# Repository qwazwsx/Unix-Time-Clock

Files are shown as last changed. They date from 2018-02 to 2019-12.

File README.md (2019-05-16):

# Introduction

This project is a fork of [Maniacal Labs Super 7 Seg](https://github.com/ManiacalLabs/Super7Seg). Please refer to that project's README for the full details of that project.

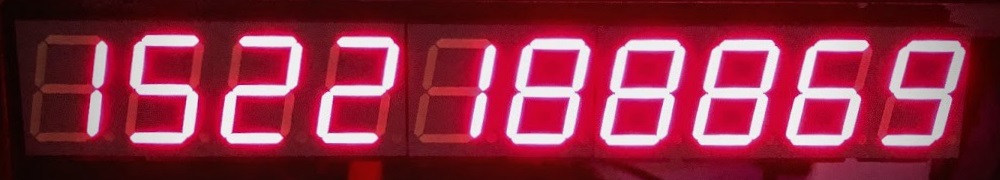
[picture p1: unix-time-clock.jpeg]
Unix Time Clock


My fork was designed with one project in mind - creating a [Unix Time Clock](https://mylifeasa.tinkerer.us/unix-time-clock-57b17d05442e). To accomplish this, I changed the [display hardware](https://github.com/dwaq/Super7Seg/tree/master/kicad/Super7Display) from 6x dual segment displays to 5x displays (12 digits to 10 digits) and changed the [controller hardware](https://github.com/dwaq/Super7Seg/tree/master/kicad/Super7Controller) from a ATMega328p to ESP32. The [Arduino firmware](https://github.com/dwaq/Super7Seg/tree/master/Firmware-ESP32) for this project is also in this repo, along with the [3D models](https://github.com/dwaq/Super7Seg/tree/master/Mount-ESP32) for mounting the project.

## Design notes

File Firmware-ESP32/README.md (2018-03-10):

# Installation & Setup Instructions

1. Copy `credentials-example.h` to `credentials.h` and fill in WiFi SSID and password
2. Adjust `#define PWM_BRIGHTNESS 255` in `display.c` if you want reduced display brightness
3. Install [Arduino core for the ESP32](https://github.com/espressif/arduino-esp32#installation-instructions)
4. Set board to "ESP32 Dev Module"
5. Select port
6. Upload code

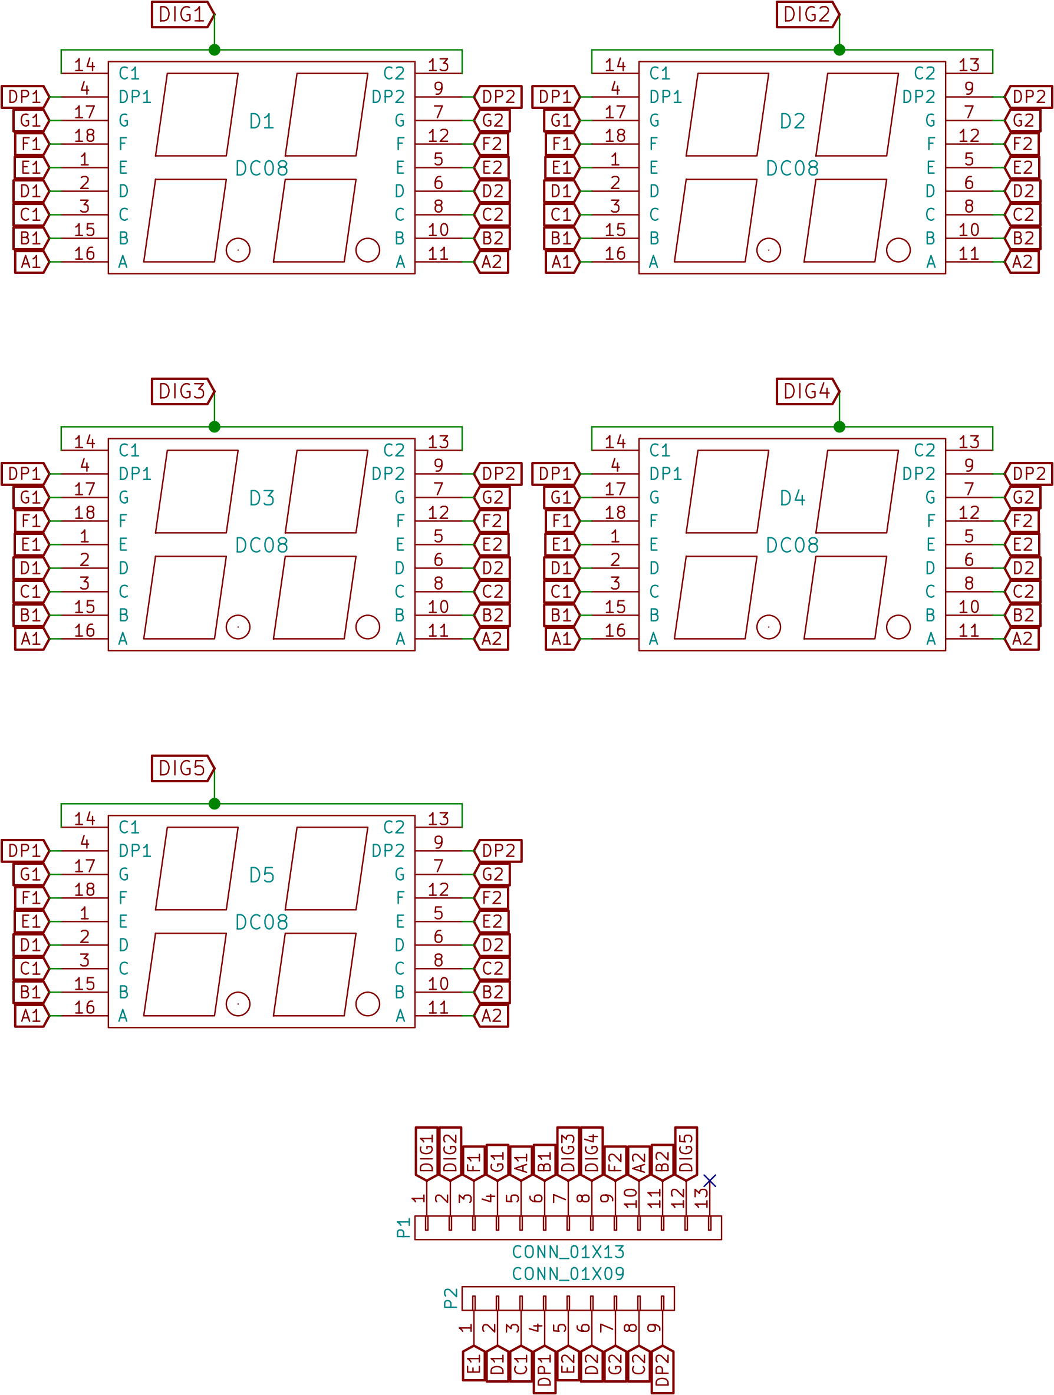
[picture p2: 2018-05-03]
kicad/Super7Display/Super7Display.sch.png

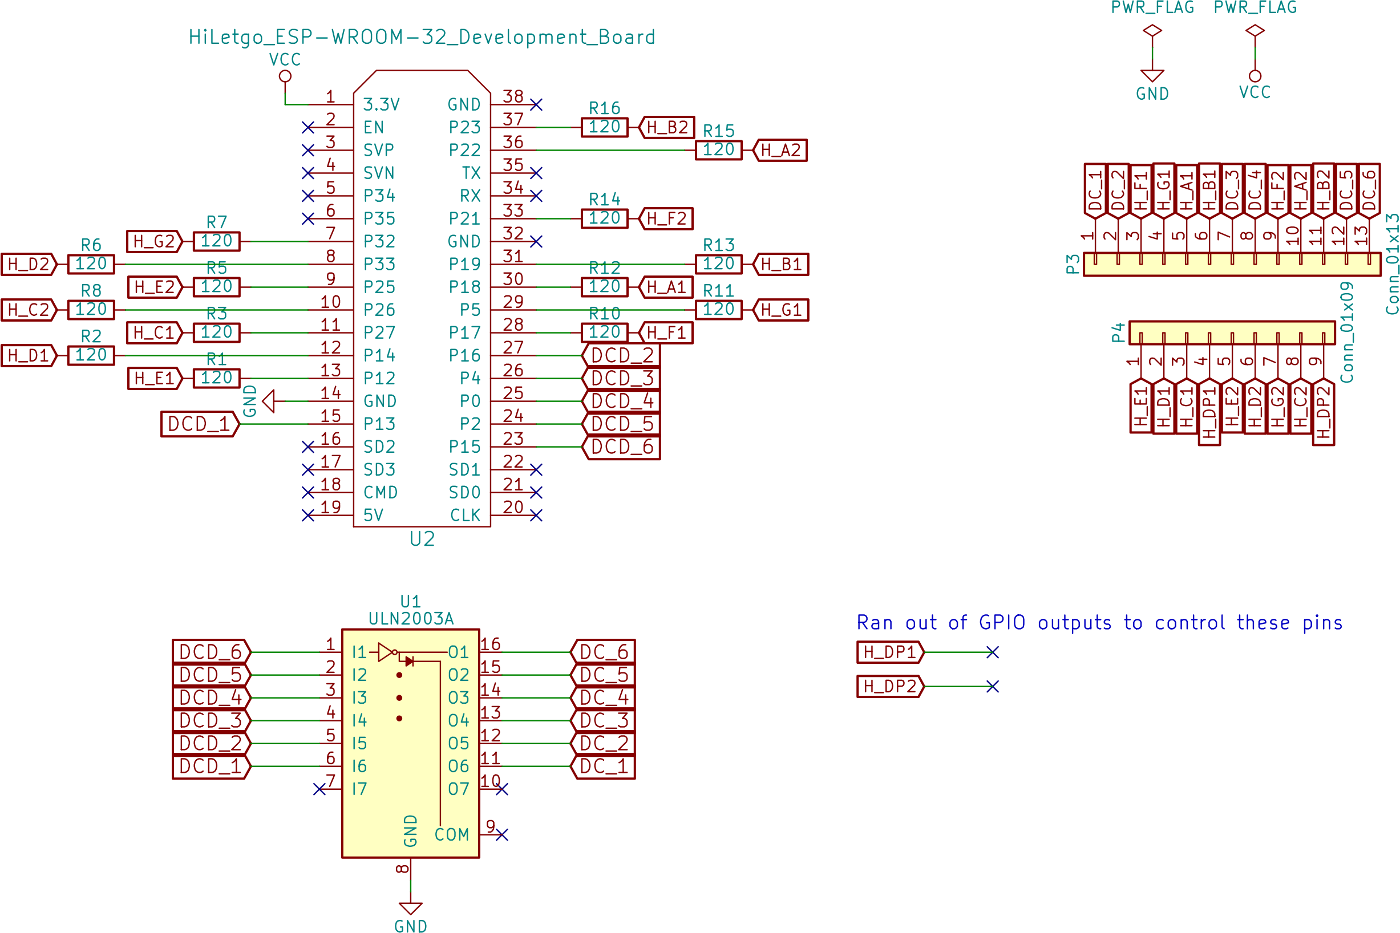
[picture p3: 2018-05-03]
kicad/Super7Controller/Super7Controller.sch.png

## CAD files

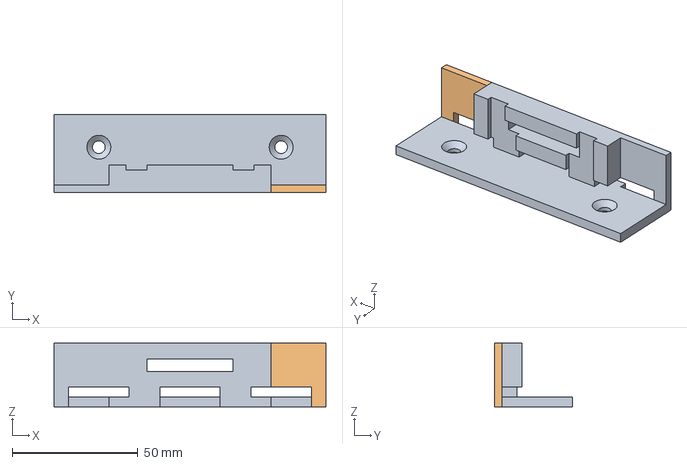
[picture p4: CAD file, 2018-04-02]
Mount-ESP32/Mount.step
108.0 x 31.0 x 25.2 mm

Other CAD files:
Mount-ESP32/Mount.f3d
Mount-ESP32/Mount.stl

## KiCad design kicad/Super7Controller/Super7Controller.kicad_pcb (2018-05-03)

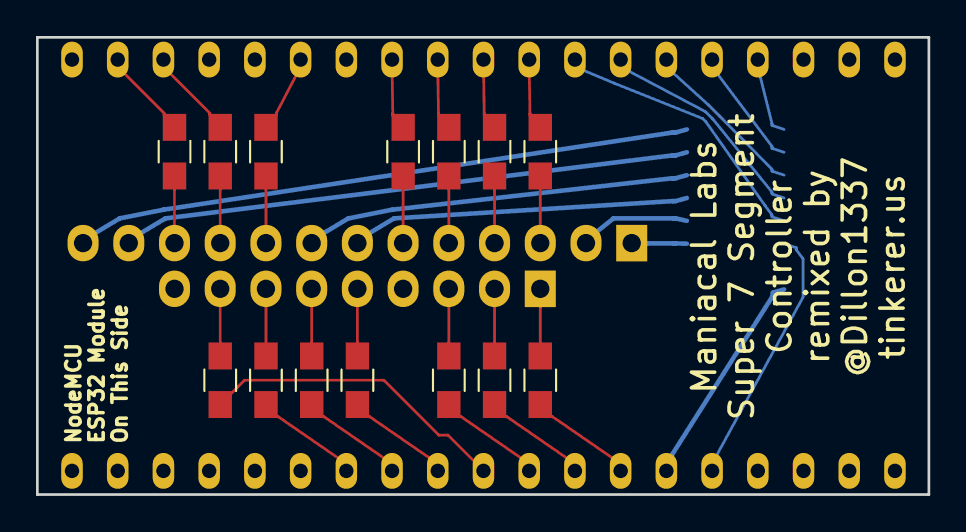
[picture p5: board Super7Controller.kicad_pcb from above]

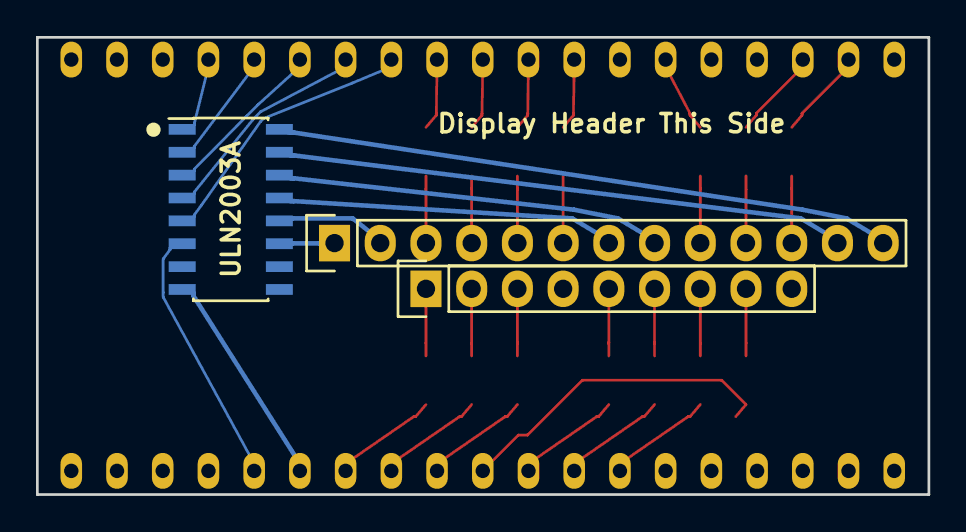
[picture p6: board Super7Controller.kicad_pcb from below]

Board: 2 copper layers, 49.5 x 25.4 mm, 18 parts (3 on the bottom side), 41 nets.

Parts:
P3: Conn_01x13; Socket_Strip_Straight_1x13
P4: Conn_01x09; Socket_Strip_Straight_1x09
R1, R2, R3, R5, R6, R7, R8, R10, R11, R12, R13, R14, R15, R16: 120; R_0805_HandSoldering
U1: ULN2003A; SOIC-16_3.9x9.9mm_Pitch1.27mm
U2: HiLetgo_ESP-WROOM-32_Development_Board; hiletgo_esp-wroom-32_development_board

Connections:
DCD_1: U1.6, U2.15
DCD_2: U1.5, U2.27
DCD_3: U1.4, U2.26
DCD_4: U1.3, U2.25
DCD_5: U1.2, U2.24
DCD_6: U1.1, U2.23
DC_1: P3.1, U1.11
DC_2: P3.2, U1.12
DC_3: P3.7, U1.13
DC_4: P3.8, U1.14
DC_5: P3.12, U1.15
DC_6: P3.13, U1.16
GND: U1.8, U2.14
H_A1: P3.5, R12.2
H_A2: P3.10, R15.2
H_B1: P3.6, R13.2
H_B2: P3.11, R16.2
H_C1: P4.3, R3.2
H_C2: P4.8, R8.2
H_D1: P4.2, R2.2
H_D2: P4.6, R6.2
H_E1: P4.1, R1.2
H_E2: P4.5, R5.2
H_F1: P3.3, R10.2
H_F2: P3.9, R14.2
H_G1: P3.4, R11.2
H_G2: P4.7, R7.2
unnamed: R1.1, U2.13
unnamed: R2.1, U2.12
unnamed: R3.1, U2.11
unnamed: R5.1, U2.9
unnamed: R6.1, U2.8
unnamed: R7.1, U2.7
unnamed: R8.1, U2.10
unnamed: R10.1, U2.28
unnamed: R11.1, U2.29
unnamed: R12.1, U2.30
unnamed: R13.1, U2.31
unnamed: R14.1, U2.33
unnamed: R15.1, U2.36
unnamed: R16.1, U2.37

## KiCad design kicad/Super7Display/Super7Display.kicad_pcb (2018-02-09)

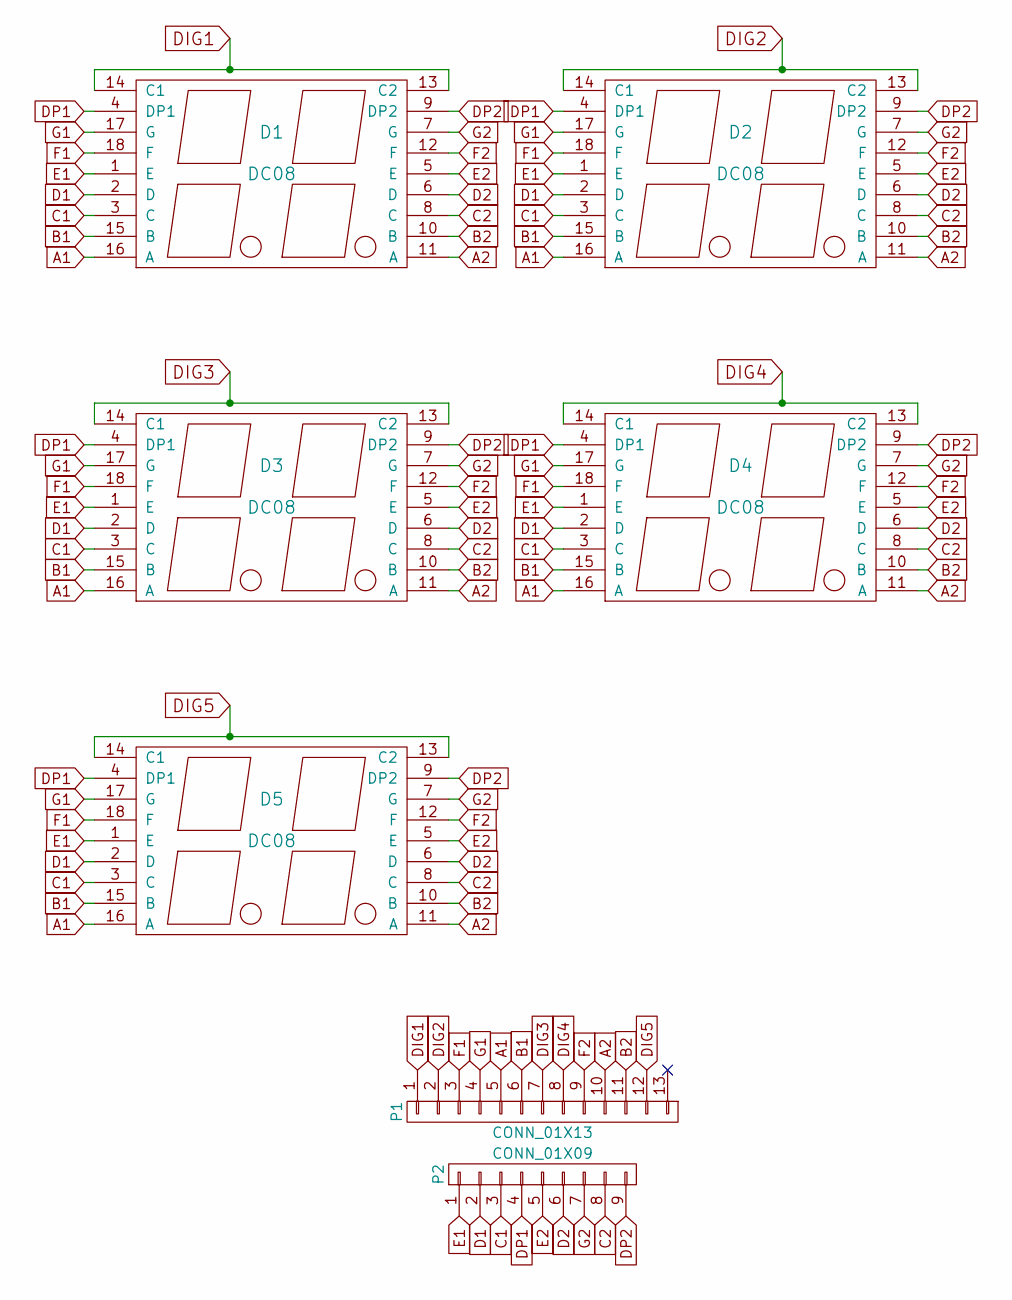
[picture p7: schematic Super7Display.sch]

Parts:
D1, D2, D3, D4, D5: DC08
P1: CONN_01X13; Socket_Strip_Straight_1x13
P2: CONN_01X09; Socket_Strip_Straight_1x09

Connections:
A1: D1.16 (A), D2.16 (A), D3.16 (A), D4.16 (A), D5.16 (A), P1.5
A2: D1.11 (A), D2.11 (A), D3.11 (A), D4.11 (A), D5.11 (A), P1.10
B1: D1.15 (B), D2.15 (B), D3.15 (B), D4.15 (B), D5.15 (B), P1.6
B2: D1.10 (B), D2.10 (B), D3.10 (B), D4.10 (B), D5.10 (B), P1.11
C1: D1.3 (C), D2.3 (C), D3.3 (C), D4.3 (C), D5.3 (C), P2.3
C2: D1.8 (C), D2.8 (C), D3.8 (C), D4.8 (C), D5.8 (C), P2.8
D1: D1.2 (D), D2.2 (D), D3.2 (D), D4.2 (D), D5.2 (D), P2.2
D2: D1.6 (D), D2.6 (D), D3.6 (D), D4.6 (D), D5.6 (D), P2.6
DIG1: D1.13 (C2), D1.14 (C1), P1.1
DIG2: D2.13 (C2), D2.14 (C1), P1.2
DIG3: D3.13 (C2), D3.14 (C1), P1.7
DIG4: D4.13 (C2), D4.14 (C1), P1.8
DIG5: D5.13 (C2), D5.14 (C1), P1.12
DP1: D1.4 (DP1), D2.4 (DP1), D3.4 (DP1), D4.4 (DP1), D5.4 (DP1), P2.4
DP2: D1.9 (DP2), D2.9 (DP2), D3.9 (DP2), D4.9 (DP2), D5.9 (DP2), P2.9
E1: D1.1 (E), D2.1 (E), D3.1 (E), D4.1 (E), D5.1 (E), P2.1
E2: D1.5 (E), D2.5 (E), D3.5 (E), D4.5 (E), D5.5 (E), P2.5
F1: D1.18 (F), D2.18 (F), D3.18 (F), D4.18 (F), D5.18 (F), P1.3
F2: D1.12 (F), D2.12 (F), D3.12 (F), D4.12 (F), D5.12 (F), P1.9
G1: D1.17 (G), D2.17 (G), D3.17 (G), D4.17 (G), D5.17 (G), P1.4
G2: D1.7 (G), D2.7 (G), D3.7 (G), D4.7 (G), D5.7 (G), P2.7

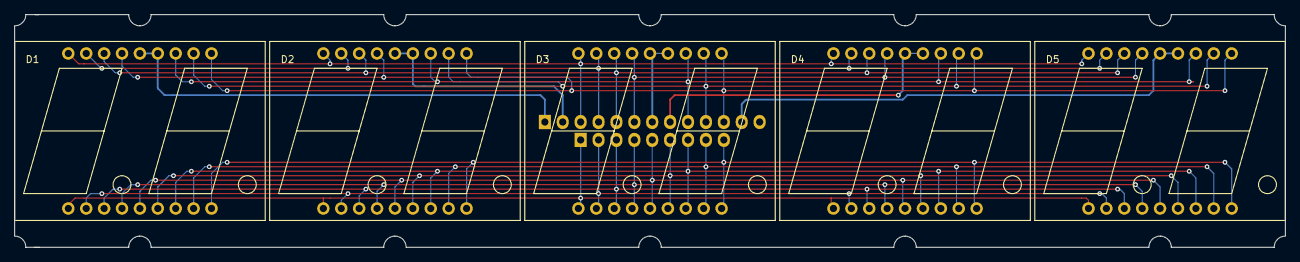
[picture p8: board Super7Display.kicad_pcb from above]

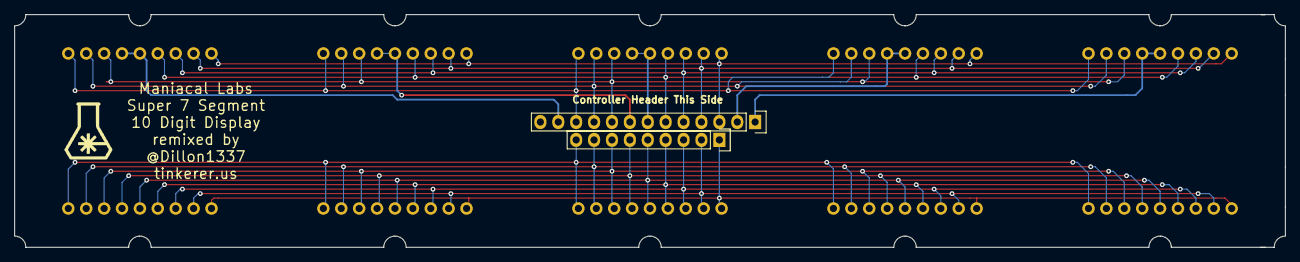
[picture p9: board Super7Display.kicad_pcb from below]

Board: 2 copper layers, 180.3 x 33.0 mm, 7 parts (2 on the bottom side), 21 nets.

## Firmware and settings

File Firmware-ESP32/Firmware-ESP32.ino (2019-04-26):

#include "getTime.h"
#include "display.h"

void setup() {
  // set up the display pins
  displaySetup();

  // start background task to get time from internet
  // normal tasks run on core 1, so run on other core - core 0
  xTaskCreatePinnedToCore(
    coreTask,   // Function to call
    "coreTask", // Name of the task
    10000,      // Stack size in words
    NULL,       // Task input parameter
    0,          // Priority of the task
    NULL,       // Task handle
    0);         // Core where the task should run

  // display connecting animation until time is set in the background
  displayConnecting();
}

void loop() {
  // get the current time and display the digits on the display
  getAndDisplayTime();
}

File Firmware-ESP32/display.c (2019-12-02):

#include "display.h"
#include "getTime.h"

// PWM settings for display brightness
// max of 255, but can reduce for a less bright display
#define PWM_BRIGHTNESS 255
// shouldn't need to change these:
#define PWM_FREQ 5000
#define PWM_RESOLUTION 8

// pinouts for common cathode 7 segment LED display:

// segment is active high
// segment | ESP32 pin
#define SEG_A1  18
#define SEG_B1  19
#define SEG_C1  27
#define SEG_D1  14
#define SEG_E1  12
#define SEG_F1  17
#define SEG_G1  5
//#define SEG_DP1 26

#define SEG_A2  22
#define SEG_B2  23
#define SEG_C2  26
#define SEG_D2  33
#define SEG_E2  25
#define SEG_F2  21
#define SEG_G2  32
//#define SEG_DP2 34

// digit is active high
// digit | ESP32 pin
#define DC_1  13
#define DC_2  16
#define DC_3  4
#define DC_4  0
#define DC_5  2
#define DC_6  15

// PWM channels cooresponding to digits
#define D_PWM_1  1
#define D_PWM_2  2
#define D_PWM_3  3
#define D_PWM_4  4
#define D_PWM_5  5
#define D_PWM_6  6

// set display pins to outputs
void displaySetup()
{
  pinMode(SEG_A1, OUTPUT);
  pinMode(SEG_B1, OUTPUT);
  pinMode(SEG_C1, OUTPUT);
  pinMode(SEG_D1, OUTPUT);
  pinMode(SEG_E1, OUTPUT);
  pinMode(SEG_F1, OUTPUT);
  pinMode(SEG_G1, OUTPUT);
  //pinMode(SEG_DP1, OUTPUT);

  pinMode(SEG_A2, OUTPUT);
  pinMode(SEG_B2, OUTPUT);
  pinMode(SEG_C2, OUTPUT);
  pinMode(SEG_D2, OUTPUT);
  pinMode(SEG_E2, OUTPUT);
  pinMode(SEG_F2, OUTPUT);
  pinMode(SEG_G2, OUTPUT);
  //pinMode(SEG_DP2, OUTPUT);

  // set up PWM on digits
  ledcAttachPin(DC_1, D_PWM_1);
  ledcSetup(D_PWM_1, PWM_FREQ, PWM_RESOLUTION);

  ledcAttachPin(DC_2, D_PWM_2);
  ledcSetup(D_PWM_2, PWM_FREQ, PWM_RESOLUTION);

  ledcAttachPin(DC_3, D_PWM_3);
  ledcSetup(D_PWM_3, PWM_FREQ, PWM_RESOLUTION);

  ledcAttachPin(DC_4, D_PWM_4);
  ledcSetup(D_PWM_4, PWM_FREQ, PWM_RESOLUTION);

  ledcAttachPin(DC_5, D_PWM_5);
  ledcSetup(D_PWM_5, PWM_FREQ, PWM_RESOLUTION);

  //ledcAttachPin(DC_6, D_PWM_6);
  //ledcSetup(D_PWM_6, PWM_FREQ, PWM_RESOLUTION);
}

// use middle segment as 10th "number" to display
#define CONNECTING 10

// delay between progress bar animations
#define CONNECTING_DELAY 100
// shortest delay so all displays are on for the same amount of time
#define DELAYTIME 1

// display a progress bar for WiFi connecting animation
void displayConnecting(void)
{
  // go right if 1; left if 0
  int right = 1;
  // index of display to light
  int n = 1;

  // continue displaying until time has been set
  while(isConnecting())
  {
    // display connecting bars "--" on n-th display
    selectDisplay(n, CONNECTING, CONNECTING);

    // count 1, 2, 3, 4, 5, 4, 3, 2
    // and then repeat
    if ((right==1) && (n<=5))
    {
      n++;
      if (n==5)
      {
        right=0;
      }
    }
    else if ((right==0) && (n>=1))
    {
      n--;
      if (n==1)
      {
        right=1;
        n=1;
      }
    }

    // each display is on for 1/10 second
    delay(CONNECTING_DELAY);
  }

  // unix time right now
  int unix_time_now = time(NULL);

  // loop until the time changes
  // while displaying all bars "----------"
  while (time(NULL) == unix_time_now)
  {
    // display connecting bars "--" on n-th display
    selectDisplay(n, CONNECTING, CONNECTING);

    // count 1, 2, 3, 4, 5
    // and then repeat
    n++;
    if (n==6)
    {
      n=1;
    }

    // shortest delay
    delay(DELAYTIME);
  }

  // start a 1 hour timer to re-sync the time from the internet
  startHardwareTimer();
}

// cycle through and display the time across all digits
void getAndDisplayTime(void)
{
  // get the current time
  unsigned int unix_time = getTime();

  // loop through the time and set each digit:

  // get lowest digit
  byte firstDigit = unix_time % 10;
  // shift over
  unix_time = unix_time / 10;
  // get next lowest digit
  byte secondDigit = unix_time % 10;
  // shift over agin for the next round
  unix_time = unix_time / 10;

  // digits are assigned right to left (LSB first)
  // digits 2 & 1
  selectDisplay(5, secondDigit, firstDigit);
  delay(DELAYTIME);

  // continue looping over the remaining digits:

  // digits 4 & 3
  firstDigit = unix_time % 10;
  unix_time = unix_time / 10;
  secondDigit = unix_time % 10;
  unix_time = unix_time / 10;
  selectDisplay(4, secondDigit, firstDigit);
  delay(DELAYTIME);

  // digits 6 & 5
  firstDigit = unix_time % 10;
  unix_time = unix_time / 10;
  secondDigit = unix_time % 10;
  unix_time = unix_time / 10;
  selectDisplay(3, secondDigit, firstDigit);
  delay(DELAYTIME);

  // digits 8 & 7
  firstDigit = unix_time % 10;
  unix_time = unix_time / 10;
  secondDigit = unix_time % 10;
  unix_time = unix_time / 10;
  selectDisplay(2, secondDigit, firstDigit);
  delay(DELAYTIME);

  // digits 10 & 9
  firstDigit = unix_time % 10;
  unix_time = unix_time / 10;
  secondDigit = unix_time % 10;
  unix_time = unix_time / 10;
  selectDisplay(1, secondDigit, firstDigit);
  delay(DELAYTIME);
}

// display a number on the selected display
// display can be between 1-5
// numbers can be between 0-9, and 10 is "--" for connecting
void selectDisplay(int display, byte number1, byte number2)
{
  // turn all digits off (PWM duty cycle = 0)
  ledcWrite(D_PWM_1, 0);
  ledcWrite(D_PWM_2, 0);
  ledcWrite(D_PWM_3, 0);
  ledcWrite(D_PWM_4, 0);
  ledcWrite(D_PWM_5, 0);
  //ledcWrite(D_PWM_6, 0);

  // set up segments while digits off,
  // so that the full digit comes up simultanously
  // (although who is going to be able to detect a couple clk cycles?)
  resetSegments();
  setSegment1(number1);
  setSegment2(number2);

  // then turn on specfic digit
  switch(display)
  {
    case 1:
      ledcWrite(D_PWM_1, PWM_BRIGHTNESS);
      break;
    case 2:
      ledcWrite(D_PWM_2, PWM_BRIGHTNESS);
      break;
    case 3:
      ledcWrite(D_PWM_3, PWM_BRIGHTNESS);
      break;
    case 4:
      ledcWrite(D_PWM_4, PWM_BRIGHTNESS);
      break;
    case 5:
      ledcWrite(D_PWM_5, PWM_BRIGHTNESS);
      break;
    //default:
      // bad - should't be here
  }
}

// reset all segments
void resetSegments(void)
{
  digitalWrite(SEG_A1, LOW);
  digitalWrite(SEG_B1, LOW);
  digitalWrite(SEG_C1, LOW);
  digitalWrite(SEG_D1, LOW);
  digitalWrite(SEG_E1, LOW);
  digitalWrite(SEG_F1, LOW);
  digitalWrite(SEG_G1, LOW);

  digitalWrite(SEG_A2, LOW);
  digitalWrite(SEG_B2, LOW);
  digitalWrite(SEG_C2, LOW);
  digitalWrite(SEG_D2, LOW);
  digitalWrite(SEG_E2, LOW);
  digitalWrite(SEG_F2, LOW);
  digitalWrite(SEG_G2, LOW);
}
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

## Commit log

2018-01-30 Remove DIG6 from schematic
    [Super7Display.sch]
2018-01-30 Remove D6 from layout
    Move right edge into place
    Top and bottom edges still need adjusted
    [Super7Display.kicad_pcb]
2018-01-30 Move mounting tabs above/below D1, D3, D5
    [Super7Display.kicad_pcb]
2018-01-30 use built-in ULN2003
    [_saved_Super7Controller.sch]
2018-01-30 DC6 is gone
    [Super7Controller.sch, _saved_Super7Controller.sch]
2018-01-30 added no connect on unused segment connector
    [Super7Display.sch]
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2018-01-31 connect ESP dev board on schematic
    [Super7Controller.sch]
2018-01-31 change resistors to surface mount
    [Super7Controller.sch]
2018-01-31 use old symbol for ULN2003A because GND is needed
    [Super7Controller.sch]
2018-01-31 change ESP pins to bidirectional to pass ERC
    [Super7Controller.sch]
2018-01-31 use SOIC footprint for ULN
    [Super7Controller.sch]
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2018-02-08 assign esp32 footprint to schematic symbol
    [Super7Controller.sch]
2018-02-08 add no connects to unused pins
    [Super7Controller.sch]
2018-02-08 read new netlist and delete all the old stuff
    [Super7Controller.kicad_pcb]
2018-02-08 remove some extra silkscreen
    [Super7Controller.kicad_pcb]
2018-02-08 move around
    [Super7Controller.kicad_pcb]
2018-02-08 move reference inside board
    [Super7Controller.kicad_pcb]
2018-02-08 add anchor
    [Super7Controller.kicad_pcb]
2018-02-08 add anchor to display also
    [Super7Display.kicad_pcb]
2018-02-08 export layout
    [Super7Controller.dsn]
2018-02-08 these ESP32 GPIOs are swappable
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2018-02-08 imported routes into kicad
    [Super7Controller.kicad_pcb]
2018-02-08 all resistor inputs are swappable
2018-02-08 make resistor inputs gate swappable
2018-02-08 move ULN to the back
    [Super7Controller.dsn, Super7Controller.kicad_pcb]
2018-02-08 import routed design into KiCad
    [Super7Controller.kicad_pcb]
2018-02-08 adjust edge cuts and remove unneeded parts
    [Super7Controller.kicad_pcb]
2018-02-08 only need one ground connection from ESP to ULN
    [Super7Controller.sch]
2018-02-08 reroute lines to match autorouter
    [Super7Controller.sch]
2018-02-08 read new netlist, some errors left
    [Super7Controller.kicad_pcb]
2018-02-08 correct errors in netlist
    [Super7Controller.kicad_pcb, Super7Controller.sch]
2018-02-08 replace long ground trace with something shorter
    [Super7Controller.kicad_pcb]
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2018-02-08 move resistor connections to make routing easier
    [Super7Controller.sch]
2018-02-08 move ULN connections to make routing easier
    [Super7Controller.sch]
2018-02-08 export netlist into layout and remove already routed lines
    [Super7Controller.kicad_pcb]
2018-02-08 autorouter worked well on resistors, ULN needs work
    [Super7Controller.dsn]
2018-02-08 move the ULN up a little
    [Super7Controller.dsn, Super7Controller.kicad_pcb]
2018-02-08 2 to 6 is better
    [Super7Controller.dsn, Super7Controller.kicad_pcb, Super7Controller.sch]
2018-02-08 Autoroute it and put it back into KiCad
    [Super7Controller.dsn, Super7Controller.kicad_pcb]
2018-02-08 remove/hide top layer silkscreen
    [Super7Controller.kicad_pcb]
2018-02-08 move silkscreen away from lines
    [Super7Controller.kicad_pcb]
2018-02-08 new gerbers lookin' good
    [Super7Controller-B.Cu.gbr, Super7Controller-B.Mask.gbr, Super7Controller-B.SilkS.gbr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]
2018-02-08 use new KiCad header instead of old one
    [Super7Controller.kicad_pcb, Super7Controller.sch]
2018-02-08 Add silkscreen for ESP32 pin 1
    [Super7Controller.kicad_pcb]
2018-02-08 add silkscreen to ULN
    [Super7Controller.kicad_pcb]
2018-02-08 new footprint for headers
    [Super7Controller.sch]
2018-02-08 latest gerbers
    [Super7Controller-B.Cu.gbr, Super7Controller-B.Mask.gbr, Super7Controller-B.SilkS.gbr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]
2018-02-08 remove anchor and change silkscreen
    [Super7Display.kicad_pcb]
2018-02-08 full size gerbers
    [Super7Display-B.Cu.gbr, Super7Display-B.Mask.gbr, Super7Display-B.SilkS.gbr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]
2018-02-08 change page size and move into center
    [Super7Display.kicad_pcb]
2018-02-08 change and move text
    [Super7Controller.kicad_pcb]
2018-02-09 regenerate gerbers
    [Super7Controller-B.Cu.gbr, Super7Controller-B.Mask.gbr, Super7Controller-B.SilkS.gbr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]
2018-02-09 put an edge cut insert in between every digit
    [Super7Display.kicad_pcb]
2018-02-09 generate new gerbers
    [Super7Display-B.Cu.gbr, Super7Display-B.Mask.gbr, Super7Display-B.SilkS.gbr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]
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2018-03-02 inverted the digit logic
    [display.c]
2018-03-02 Use DP1 pin for C2
    GPIOs 34 and 35 are input only (GPI??)
    Not enough pins to control everything
    Since one "bad" pin was already DP2, use DP1's pin to control the other "bad" pin, C2
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2018-03-03 fix display brightness by delaying between each display
    [display.c]
2018-03-03 constantly set time
    doesn't need to be done this way. would be better if it was set every second instead
    [Firmware-ESP32.ino]
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2018-03-10 (BUG FIX): DC_6 is on P15, PIN 23
    [display.c]
2018-03-10 replace hardcoded PWM channels with #defines
    [display.c]
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2018-04-02 3D printed bracket for mounting the ESP32 controller and 10 digit display
    File is heavily modified since I last printed it. My 3D print required a lot of changes with a sharp blade. I tried to miror those changes in this file but I haven't printed this design to know if it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
    [Mount.f3d, Mount.step, Mount.stl]
2018-04-02 restart ESP32 if it doesn't connect to WiFi at startup
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2018-04-02 set up hardware timer aligned with actual time
    performed automatically at startup
2018-05-03 Apply bodge wire fix to controller PCB
    Decimal points are no longer connected
    [Super7Controller.kicad_pcb, Super7Controller.sch]
2018-05-03 regenerate controller gerbers
    [Super7Controller-B.Cu.gbr, Super7Controller-B.Mask.gbr, Super7Controller-B.SilkS.gbr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]
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2019-04-25 constantly get the time and then display it
    instead of only getting the time every second from the hardware timer
2019-04-26 Spread out the digit calculation over the displays & refresh time every hour
    Last commit heavily front-loaded the time calculation. It got the time and determined every digit to display AND THEN displayed each of those digits. Now it gets the time and the two digits for one display, then the two digits for the next display, etc. This should prevent the glitches in the display updates.
    This also reuses the hardware timer to re-sync the time from the internet every hour. All it does is set a flag so the other core will get the time so this also shouldn't affect the display.
    [Firmware-ESP32.ino, display.c]
2019-05-16 use the hardware timer to update the time from the internet every hour
2019-05-23 Change divider on HW timer from 1us to 100us
    This should help to prevent the timerAlarmWrite issue. interruptAt is now 26 bits instead of 32 bits
